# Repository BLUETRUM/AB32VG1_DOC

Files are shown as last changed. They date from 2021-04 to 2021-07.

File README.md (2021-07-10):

# AB32VG1_DOC

#### 介绍

本项目提供了 AB32VG1 相关的资料

可以加 Q 群与更多人进行讨论 785592558

**购买链接**

https://item.taobao.com/item.htm?spm=a1z10.5-c-s.w4002-23299268143.37.7c8d4a3cdrXWUQ&id=640432786573

**文档资料**

+ test_program; 测试程序
+ AB32VG1_DataSheet;
+ AB32VG1_Prougen_Circuit; 电路板资料
+ AB32VG1_Prougen_Schematic; 原理图资料
+ AB32VG1_Register; 寄存器资料
+ AB32VG1_User_Manual;

**工具资料**

V01 的板子需要参考下面的安装说明安装 CP210x_Windows_Drivers 的驱动，V02 的板子不需要特别的驱动

[安装说明](https://ab32vg1-example.readthedocs.io/zh/latest/experiment.html)

+ CP210x_Windows_Drivers
+ Downloader

**更多信息**

+ https://ab32vg1-example.readthedocs.io/zh/latest/
+ https://club.rt-thread.org/ask/search.html?module=article&type=new&keyword=ab32vg1

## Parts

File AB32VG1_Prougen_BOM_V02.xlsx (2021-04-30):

Item # | Comment | Band | Footprint | Quantity | Designator | 购买链接
1 | IC_AB32VG1 | 中科蓝讯 | LQFP-48_7x7x05P | 1 | U2
2 | IC_CH340E | SILICON LABS(芯科) | QFN-28_5x5x05P | 1 | U1 | https://item.szlcsc.com/100866.html
3 | IC_PAI121M31 | 荣湃 | pai121M31 | 1 | U4 | https://item.szlcsc.com/478035.html
4 | 电容0402_102 | 村田 | C0402 | 1 | C25 | https://item.szlcsc.com/78074.html
5 | 电容0402_105 | 村田 | C0402 | 8 | C6, C8, C9, C13, C15, C16, C17, C18 | https://item.szlcsc.com/364357.html
6 | 电容0603_106 | 村田 | C0603 | 5 | C3, C4,C11, C19, C20 | https://item.szlcsc.com/91238.html
7 | 电容0603_104 | 华新科 | C0603 | 5 | C5, C12, C14,C21,C23 | https://item.szlcsc.com/108788.html
8 | 电容0805_22uF/10V | 风华 | 805 | 2 | C22, C24 | https://item.szlcsc.com/516498.html
9 | 电容1210_47uF(476) ±20% 16V | TAIYO YUDEN(太诱) | 2010 | 1 | CE1 | https://item.szlcsc.com/90327.html
10 | 电阻0402_0R | 国巨 | R0402 | 3 | R11,R13,L1 | https://item.szlcsc.com/107446.html
11 | 电阻0603_6.8K | 厚声 | R0603 | 2 | R2, R10 | https://item.szlcsc.com/23939.html
12 | 电阻0603_200R | 厚声 | R0603 | 3 | R4, R22, R23 | https://item.szlcsc.com/25960.html
13 | 电阻0603_3K | 国巨 | R0603 | 2 | R5, R6 | https://item.szlcsc.com/478426.html
14 | 电阻0603_1K | 厚声 | R0603 | 3 | R7, R17,R19 | https://item.szlcsc.com/21904.html
15 | 电阻0603_470K | 厚声 | R0603 | 1 | R8 | https://item.szlcsc.com/26342.html
16 | 电阻0603_5.1K | 厚声 | R0603 | 1 | R9 | https://item.szlcsc.com/26743.html
17 | 电阻0603_10K | 厚声 | R0603 | 1 | R12 | https://item.szlcsc.com/26547.html
18 | 电阻0603_0R | 华新科 | R0603 | 1 | R14,R21 | https://item.szlcsc.com/307816.html
19 | 电阻0603_2.2K | 厚声 | R0603 | 2 | R15, R16 | https://item.szlcsc.com/4597.html
20 | 电阻0603_470R | 国巨 | R0603 | 2 | R18, R20 | https://item.szlcsc.com/115913.html
21 | 10uH | FH(风华) | CD32 | 1 | L4 | https://item.szlcsc.com/150566.html
22 | 贴片电感,220nH ±10%,CMI160808VR22KT | 顺络 | L0603 | 1 | L5 | https://item.szlcsc.com/23202.html
23 | 100nH | 顺络 | L0603 | 1 | L6 | https://item.szlcsc.com/75429.html
24 | LED贴片3528共阳高亮红绿蓝RGB三色光 | 美华电子 | RGB | 1 | LED | https://item.szlcsc.com/400142.html
25 | LED0603_红 | 国星光电 | 0603_LED_S1 | 2 | D1, D5 | https://item.szlcsc.com/85432.html
26 | LED0603_蓝 | 国星光电 | 0603_LED_S1 | 2 | D2, D3 | https://item.szlcsc.com/85435.html
27 | MOS(场效应管) / AO3401A | UMW(友台半导体) | SOT-23 | 1 | Q1 | https://item.szlcsc.com/324136.html
28 | 三极管 / SS8050 | CJ（江苏长电/长晶） | SOT-23 | 2 | Q2, Q3 | https://item.szlcsc.com/2507.html
29 | 通用二极管,1N4007 | TWGMC(台湾迪嘉) | DO-213AB | 1 | D4 | https://item.szlcsc.com/774186.html
30 | 开关二极管,1N4148W | 晶导微电子 | SOD123 | 1 | D6 | https://item.szlcsc.com/116348.html
31 | 稳压管_MM1Z5B1 | ST(先科) | SOD123 | 1 | D7 | https://item.szlcsc.com/109361.html
32 | 排针排母2.54mm 1*10P 直 排母 镀金 | BOOMELE(博穆精密) | HDR1X10 | 1 | IOH | https://item.szlcsc.com/36418.html
33 | 排针排母 / 2.54X8.5FH/1X8P/Y型/180°/PC3.2 | 华宇创 | HDR1X8 | 2 | IOL, POWER | https://item.szlcsc.com/326597.html
34 | 排针排母2.54*8.5排母 1*6P S/T | MINTRON(明硕) | HDR1X6 | 1 | ANALOG IN | https://item.szlcsc.com/333720.html
35 | 红外遥控接收头,IRM-56384 | EVERLIGHT(台湾亿光) | IC-REM | 1 | IRDA | https://item.szlcsc.com/73157.html
36 | 插针单排_2.54*1*5_5P | 台湾兴飞 | HDR1X5 | 1 | J1 | https://item.szlcsc.com/525918.html
37 | 插针单排_2.54*1*2_2P | 台湾兴飞 | PIN2 | 2 | J3, J19 | 上述链接为40pin单排插针，需要手动成型；三个板子合计用1个；
38 | 插针单排_2.54*1*3_3P | 台湾兴飞 | HDR1X3 | 1 | P3
39 | 插针双排_2.54*2*4_8P | BOOMELE(博穆精密) | HDR2X4 | 2 | P1, P2 | https://item.szlcsc.com/829951.html
40 | 插针双排_2.54*2*3_6P | BOOMELE(博穆精密) | HDR2X3 | 1 | P4 | 上述链接为2*8pin双排插针，需要手动成型；一个板子合计用2个；
41 | 插针双排_2.54*2*2_4P | BOOMELE(博穆精密) | HDR2X2 | 2 | P5, P6
42 | SMT_按键轻触开关,6*6*5 | 韩荣 | SMD | 4 | S1,S2,S3,S4 | https://item.szlcsc.com/84370.html
43 | 自弹式TF卡座 TF外焊式内存卡卡座_TF PUSH | SHOU HAN(首韩) | TF3 | 1 | TF Card | https://item.szlcsc.com/372553.html
44 | USB连接器,TYPEC-304-BCP16 | XUNPU(讯普) | Type-C-DIP | 1 | TYPE-C | https://item.szlcsc.com/763636.html
45 | USB A母座90°DIP 内扣型,KH-AF90DIP-112 | kinghelm(金航标) | USB-A | 1 | USB | https://item.szlcsc.com/516655.html
46 | φ3.5 4脚贴片三节耳机插座,带定位柱_PJ-320D | SHOU HAN(首韩) | LINER_09 | 1 | AUDIO | https://item.szlcsc.com/427892.html
47 | 贴片晶体谐振器(无源),TAXM26M4RCBCCT2T, 26MHz_9pF_10ppm | TAE(雅晶鑫) | XTAL_SMT - 3225 | 1 | Y1 | https://item.szlcsc.com/175438.html
48 | 晶振32.768K_12.5pF | LIMING(利明) | XTAL-3X8 | 1 | Y2 | https://item.szlcsc.com/760833.html
50 | 跳线帽 |  |  | 8 |  | https://item.szlcsc.com/142697.html
51 | 静电袋 |  |  | 1 |  | https://item.szlcsc.com/252826.html
51 | 不焊接 |  |  | 14 | J2, J4,C1, C2, C7, C10, C26,ED1, ED2, ED3, L2, L3,R22,R23

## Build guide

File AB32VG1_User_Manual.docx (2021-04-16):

# AB32VG1开发板

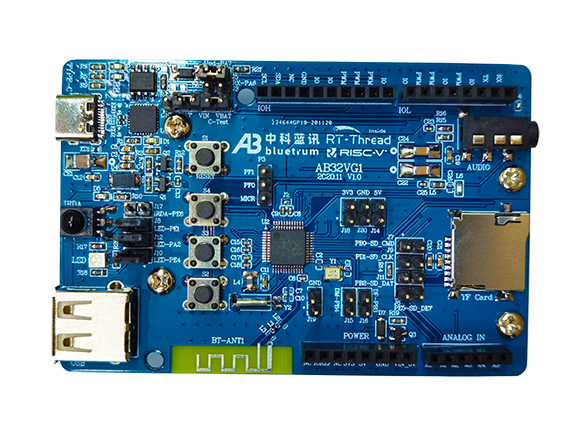
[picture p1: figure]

### 用户手册

## 1. 概述

AB32VG1开发板是以中科蓝讯（Bluetrum）公司推出的基于RISC-V架构的高配置芯片AB5301A为核心所组成的。

## 板上资源：

- CPU：AB5301A；（LQFP48封装，主频120M，片上集成RAM 192K, flash 8Mbit，ADC，PWM，USB，UART，IIC等资源）
- 搭载蓝牙模块
- 搭载FM模块
- 一路TF Card接口
- 一路USB接口
- 一路IIC接口
- 一路音频接口(美标CTIA)
- 六路ADC输入引脚端子引出
- 六路PWM输出引脚端子引出
- 一个全彩LED灯模块，一个电源指示灯，三个烧录指示灯
- 一个IRDA（红外接收端口）
- 一个Reset按键，三个功能按键(通用版为两个功能按键)
- 板子规格尺寸：6cm*9cm
- I/O口通过2.54MM标准间距引出，同时兼容Arduino Uno扩展接口，方便二次开发

板上所有的硬件特性能快速帮助评估AB5301A所有外设和衍生开发新的应用。

## 2. 电路接口说明

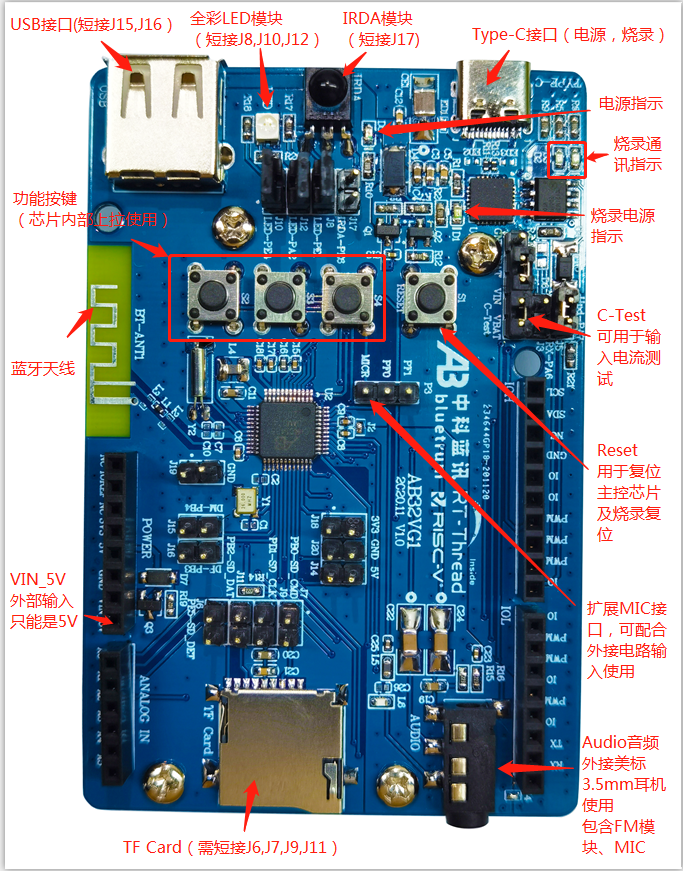
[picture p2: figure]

##### 2.1 电源供给

开发板采用外部5V电源输入，用Type-C接口及USB接口提供5V输入；兼容Arduino Uno扩展接口VIN_5V也支持5V输入；

供电时需用跳线帽连接J1的VIN与VBAT两引脚，及C-TEST端口；

该端口若串入电流表，可用于开发板的总电流测试；

Note：兼容Arduino Uno扩展接口的外部5V电源输入，仅限于5V输入，不支持宽电压输入！！！

##### 2.2 程序烧录

开发板通过Type-C接口进行烧录，烧录采用单线烧录（1 wire program&debug）；

烧录程序时需用跳线帽连接J5及J1的VBAT’与VIN两引脚；

J5为连接待烧录芯片

J1两引脚为烧录端供电

##### 2.3 时钟源

开发板由两个始终源提供时钟

Y1：26MHz晶振

Y2：32.768KHz晶振

##### 2.4 复位方式

开发板通过Reset按键复位电源的方式复位

故，不兼容Arduino Uno扩展接口的Reset，对应引脚NC；

##### 2.5 Audio音频接口

Audio音频接口集成了左右声道，MIC及FM与一体，需要配合接入美标（CTIA）3.5mm的耳机使用；

NOTE：

1. 使用FM模块时，必须插入美标（CTIA）耳机线使用，耳机线充当FM天线；
2. 使用麦克风功能时，需要使用带Mic的美标（CTIA）耳机；

##### 2.6 全彩LED模块

使用该模块时，需要用跳线帽连接J8、J10、J12；不使用时，去除跳线帽，芯片端分别可以引脚分别可以配置成相应PWM使用；

##### 2.7 模拟输入

开发板提供六路模拟输入，并同时兼容Arduino Uno扩展接口的六路模拟输入（ANALOG IN）；分别对应AB5301A的PB1,PB2,PE5,PE6,PE7及PWKEY；

##### 2.8 PWM输出

开发板提供六路PWM输出，并同时兼容Arduino Uno扩展接口的六路PWM输出，分别对应AB5301A的PA2,PE4,PA6,PE0,PE1,PB0;

其中，PE1,PE4,PA2 用跳线帽连接可使用全彩LED模块；

##### 2.9 USB接口

开发板具有一个USB外设接口，用户也可以用该接口进行外部电源输入供电；若使用USB通讯时，需使用跳线连接J15,J16；不使用时，去除跳线帽，芯片端的PB3,PB4可以做IO口外接使用；

##### 2.10 IRDA模块

开发板有一个IDRA（红外接收端口）模块，用户可以通过跳线帽连接J17使用；

不使用时，去除跳线帽，芯片端的PE6可以做ADC使用；

##### 2.11 TF card接口

开发板有一个TF card接口，用户使用时，需用跳线帽连接J6,J7,J9,J11；去除跳线帽，芯片端的PB1,PB2,PE5可以做ADC外接使用；PB0可以做PWM外接；

## 3. 接口定义

接口定义具体如下图：

其中，双PIN标示部分，如IRDA-PE6，代表IRDA端为红外接收端，PE6代表AB5301A芯片端PE6口；

单PIN标示部分，分别标示该引脚定义，如DP，代表USB接口的DP脚；再如PF1，代表AB5301A芯片端引出的PF1口；

另，该板部分兼容Arduino Uno扩展接口，该定义见如下表格：

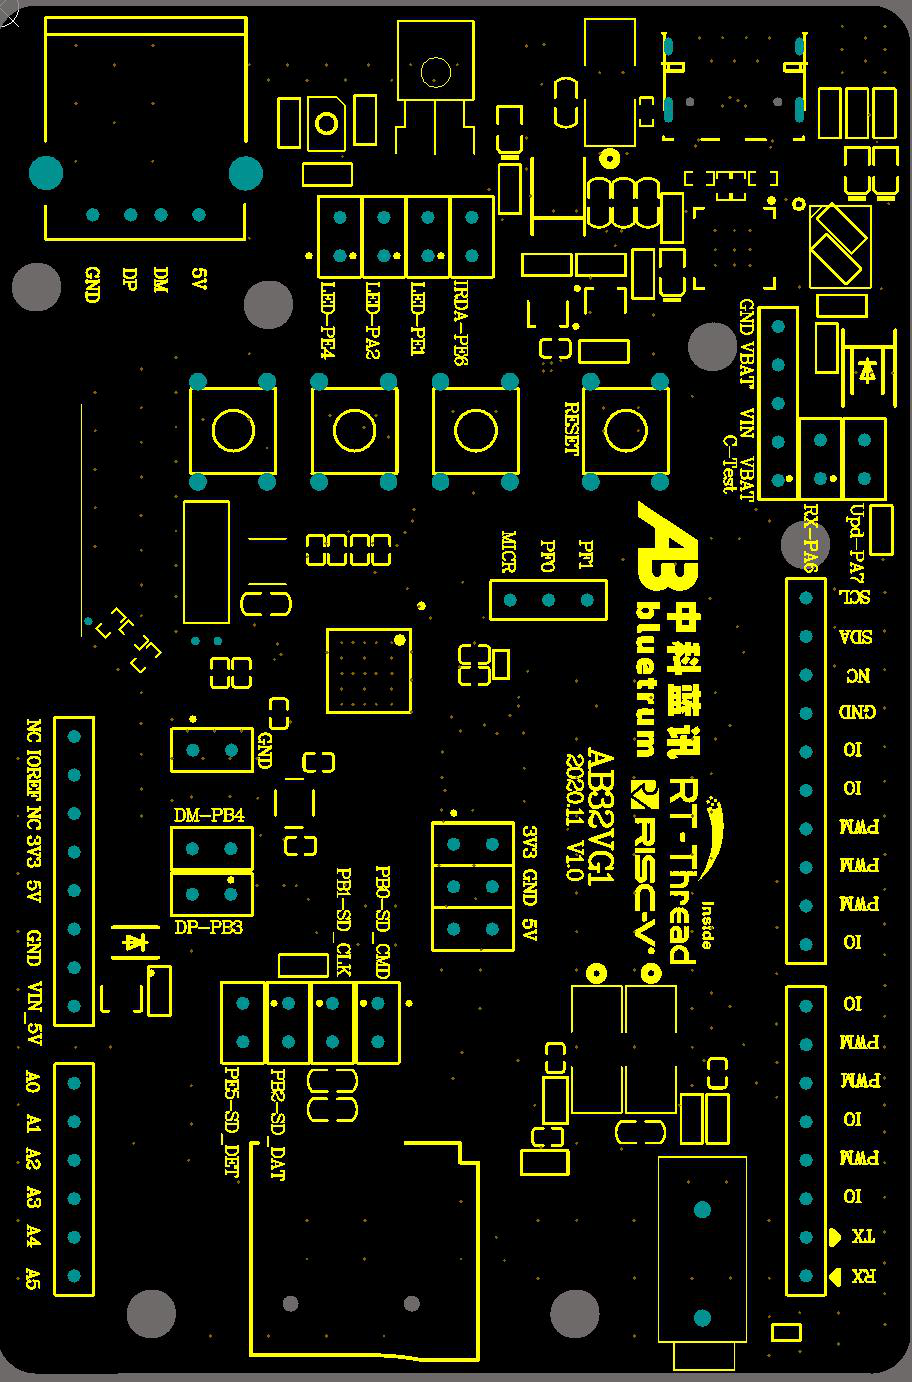
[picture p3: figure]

IOH | | IOL | | Power | | ANALOG IN
SCL | PE3 | IO | PF0 | NC | NC | A5 | PE7
SDA | PE2 | PWM | PE0 | IOREF | +5V | A4 | PE6
NC | NC | PWM | PE1 | NC | NC | A3 | PE5
GND | GND | IO | PA5 | 3V3 | 3V3 | A2 | PWKEY
IO | PA0 | PWM | PB0 | 5V | +5V | A1 | PB1
IO | PA1 | IO | PF1 | GND | GND | A0 | PB2
PWM | PA2 | TX | PA4 | GND | GND
PWM | PE4 | RX | PA3 | VIN_5V | 5V输入
PWM | PA6
IO | PA7

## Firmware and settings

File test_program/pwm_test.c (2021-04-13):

#include <rtthread.h>
#include <rtdevice.h>

#define PWM_DEV_NAME        "t5pwm"  /* PWM设备名称 */
#define PWM_DEV_CHANNEL     1       /* PWM通道 */

struct rt_device_pwm *pwm_dev;      /* PWM设备句柄 */

static int pwm_led_sample(int argc, char *argv[])
{
    rt_uint32_t period, pulse, dir;

    period = 500000;    /* 周期为0.5ms，单位为纳秒ns */
    dir = 1;            /* PWM脉冲宽度值的增减方向 */
    pulse = 0;          /* PWM脉冲宽度值，单位为纳秒ns */

    /* 查找设备 */
    pwm_dev = (struct rt_device_pwm *)rt_device_find(PWM_DEV_NAME);
    if (pwm_dev == RT_NULL)
    {
        rt_kprintf("pwm sample run failed! can't find %s device!\n", PWM_DEV_NAME);
        return RT_ERROR;
    }

    /* 设置PWM周期和脉冲宽度默认值 */
    rt_pwm_set(pwm_dev, PWM_DEV_CHANNEL, period, pulse);
    /* 使能设备 */
    rt_pwm_enable(pwm_dev, PWM_DEV_CHANNEL);

    while (1)
    {
        rt_thread_mdelay(50);
        if (dir)
        {
            pulse += 5000;      /* 从0值开始每次增加5000ns */
        }
        else
        {
            pulse -= 5000;      /* 从最大值开始每次减少5000ns */
        }
        if (pulse >= period)
        {
            dir = 0;
        }
        if (0 == pulse)
        {
            dir = 1;
        }

        /* 设置PWM周期和脉冲宽度 */
        rt_pwm_set(pwm_dev, PWM_DEV_CHANNEL, period, pulse);
    }
}
/* 导出到 msh 命令列表中 */
MSH_CMD_EXPORT(pwm_led_sample, pwm sample);

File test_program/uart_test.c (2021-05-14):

// 需要取消 uart_irq_process 对下面这段代码的注释
// serial->parent.rx_indicate(&serial->parent, rx_length);
#include <rtthread.h>

#define SAMPLE_UART_NAME       "uart1"

/* 用于接收消息的信号量 */
static struct rt_semaphore rx_sem;
static rt_device_t serial;

/* 接收数据回调函数 */
RT_SECTION(".irq.usart")
static rt_err_t uart_input(rt_device_t dev, rt_size_t size)
{
    /* 串口接收到数据后产生中断，调用此回调函数，然后发送接收信号量 */
    rt_sem_release(&rx_sem);

    return RT_EOK;
}

static void serial_thread_entry(void *parameter)
{
    char ch;

    while (1)
    {
        /* 从串口读取一个字节的数据，没有读取到则等待接收信号量 */
        while (rt_device_read(serial, -1, &ch, 1) != 1)
        {
            /* 阻塞等待接收信号量，等到信号量后再次读取数据 */
            rt_sem_take(&rx_sem, RT_WAITING_FOREVER);
        }
        /* 读取到的数据通过串口错位输出 */
        ch = ch + 1;
        rt_device_write(serial, 0, &ch, 1);
    }
}

static int uart_sample(int argc, char *argv[])
{
    rt_err_t ret = RT_EOK;
    char uart_name[RT_NAME_MAX];
    char str[] = "hello RT-Thread!\r\n";

    if (argc == 2)
    {
        rt_strncpy(uart_name, argv[1], RT_NAME_MAX);
    }
    else
    {
        rt_strncpy(uart_name, SAMPLE_UART_NAME, RT_NAME_MAX);
    }

    /* 查找系统中的串口设备 */
    serial = rt_device_find(uart_name);
    if (!serial)
    {
        rt_kprintf("find %s failed!\n", uart_name);
        return RT_ERROR;
    }

    /* 初始化信号量 */
    rt_sem_init(&rx_sem, "rx_sem", 0, RT_IPC_FLAG_FIFO);
    /* 以中断接收及轮询发送模式打开串口设备 */
    rt_device_open(serial, RT_DEVICE_FLAG_INT_RX);
    /* 设置接收回调函数 */
    rt_device_set_rx_indicate(serial, uart_input);
    /* 发送字符串 */
    rt_device_write(serial, 0, str, (sizeof(str) - 1));

    /* 创建 serial 线程 */
    rt_thread_t thread = rt_thread_create("serial", serial_thread_entry, RT_NULL, 1024, 25, 10);
    /* 创建成功则启动线程 */
    if (thread != RT_NULL)
    {
        rt_thread_startup(thread);
    }
    else
    {
        ret = RT_ERROR;
    }

    return ret;
}
/* 导出到 msh 命令列表中 */
MSH_CMD_EXPORT(uart_sample, uart device sample);

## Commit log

2021-04-13 新建 test_program
2021-04-13 上传测试程序
2021-04-13 删除文件 test_program/.keep
2021-04-13 更新购买链接；添加测试程序
2021-04-16 更新文档
2021-04-16 删除文件 AB32VG1_user_manual.pdf
2021-04-30 重命名 AB32VG1_Prougen_Schematic_V1_0.pdf 为 AB32VG1_Prougen_Schematic_V01.pdf
2021-04-30 新版硬件资料
    [AB32VG1_V02.PcbDoc]
2021-04-30 重命名 AB32VG1_V02.pdf 为 AB32VG1_Prougen_Schematic_V02.pdf
2021-04-30 重命名 AB32VG1_V02.PcbDoc 为 AB32VG1_Prougen_Circuit_V02.PcbDoc
    [AB32VG1_Prougen_Circuit_V02.PcbDoc]
2021-04-30 添加BOM
    [AB32VG1_Prougen_BOM_V02.xlsx]
2021-04-30 新的下载器
2021-05-14 上传测试代码
2021-06-18 更新 downloader
